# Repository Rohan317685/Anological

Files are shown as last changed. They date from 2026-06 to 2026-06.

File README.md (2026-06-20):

# Analogical 

This is Analogical; a project I've made for chipless.hackclub.com, The main goal of this project was to learn analog and not use a microcontroller! 

It is a 6 node transistor only signal network where each block drives, perturbs and destabalises the next creating a really chaotic annalog behaviour which cannot be replicated with a MCU

schematic

pcb

pcb render

| Item | Item description | Quantity | Price | Link |
|---|---|---|---|---|
| PCB | Printed Circuit Board | 5 | $5.5 | https://jlcpcb.com/ |
| 10uF capacitor | for the led transistor | 20 | $1.16 | https://www.lcsc.com/product-detail/C669099.html |
| 100nF capacitor | For decoupling | 50 | $1.07 | https://www.lcsc.com/product-detail/C89258.html |
| 10uF Electrolytic Capacitor | For decoupling | 50 | $ 1.05  | https://www.lcsc.com/product-detail/C2841113.html |
| Red LED | For showing the patterns | 20 | $ 0.73  | https://www.lcsc.com/product-detail/Light-Emitting-Diodes-LED_red_C99772.html |
| 1n41482 diode | For reverse polarity protection | 5 | $0.73 | https://www.lcsc.com/product-detail/C112342.html |
|  Pin header 1x2 | For power supply | 20 | $ 0.61  | https://www.lcsc.com/product-detail/C124375.html |
| Transistor JSCJ C1815 120~240-TA | For the transistors ofc | 40 | $  1.04 | https://www.lcsc.com/product-detail/C382004.html |
| Resistor 100k | For resisting | 100 | $0.29 | https://www.lcsc.com/product-detail/C416061.html |
| Resistor 1k | For resisting aswell | 100 | $ 0.42  | https://www.lcsc.com/product-detail/Chip-Resistor-Surface-Mount_1KR-1000-1_C95781.html |
| AMS1117-3.3 | Voltage regulator | 5 | $ 0.99  | https://www.lcsc.com/product-detail/C6186.html |
|LCSC fees |Shipping/handling fees | N/A |$7.89 | lcsc.com |

I have used the cheapest shipping options and it comes to a total off: $22.48

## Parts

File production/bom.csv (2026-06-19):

Designator | Footprint | Quantity | Value | LCSC Part #
C1, C2, C3, C4, C5, C6 | 0805 | 6 | 10uF
C10, C9 | 0805 | 2 | 100nF
C7, C8 | CP_Radial_D5.0mm_P2.00mm | 2 | 10uF
D1, D2, D3, D4, D5, D6 | LED_D3.0mm | 6 | LED
D7 | D_SOD-123 | 1 | 1N4148W
J1 | PinHeader_1x02_P2.54mm_Vertical | 1 | Conn_01x02_Pin
Q1, Q10, Q11, Q12, Q13, Q14, Q15, Q16, Q17, Q18, Q2, Q3, Q4, Q5, Q6, Q7, Q8, Q9 | TO-92_Inline | 18 | Q_NPN_BCE
R1, R11, R12, R13, R14, R15, R19, R20, R21, R22, R23, R24, R3, R4, R5, R7, R8, R9 | 0805 | 18 | 100k
R10, R16, R17, R18, R2, R6 | 0805 | 6 | 1k
U1 | SOT-223-3_TabPin2 | 1 | AMS1117-3.3

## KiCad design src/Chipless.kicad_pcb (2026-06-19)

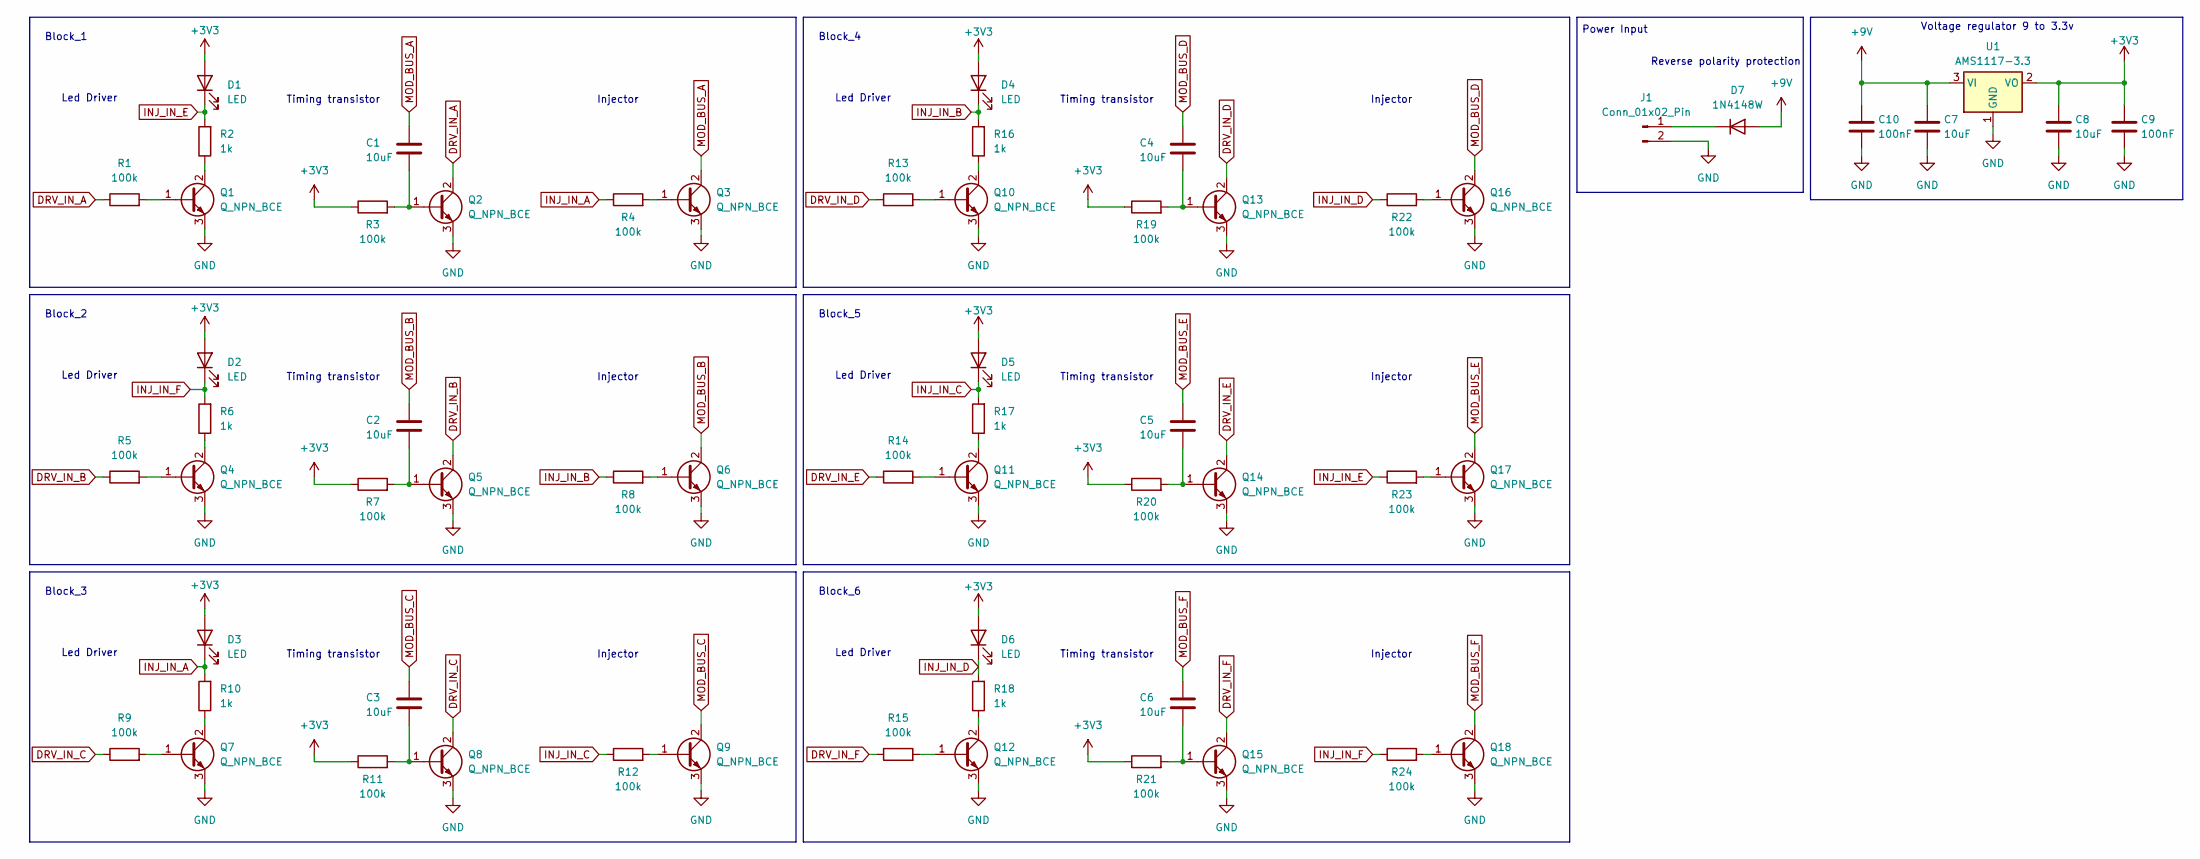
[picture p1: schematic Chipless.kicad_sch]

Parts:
C1, C2, C3, C4, C5, C6: 10uF; C_0805_2012Metric
C7, C8: 10uF; CP_Radial_D5.0mm_P2.00mm
C9, C10: 100nF; C_0805_2012Metric
D1, D2, D3, D4, D5, D6: LED; LED_D3.0mm
D7: 1N4148W; D_SOD-123
J1: Conn_01x02_Pin; PinHeader_1x02_P2.54mm_Vertical
Q1, Q2, Q3, Q4, Q5, Q6, Q7, Q8, Q9, Q10, Q11, Q12, Q13, Q14, Q15, Q16, Q17, Q18: Q_NPN_BCE; TO-92_Inline
R1, R3, R4, R5, R7, R8, R9, R11, R12, R13, R14, R15, R19, R20, R21, R22, R23, R24: 100k; R_0805_2012Metric
R2, R6, R10, R16, R17, R18: 1k; R_0805_2012Metric
U1: AMS1117-3.3; SOT-223-3_TabPin2

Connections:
+3V3: C8.1, C9.1, D1.2 (A), D2.2 (A), D3.2 (A), D4.2 (A), D5.2 (A), D6.2 (A), R3.1, R7.1, R11.1, R19.1, R20.1, R21.1, U1.2 (VO)
+9V: C7.1, C10.1, D7.2 (A), U1.3 (VI)
DRV_IN_A: Q2.2 (C), R1.1
DRV_IN_B: Q5.2 (C), R5.1
DRV_IN_C: Q8.2 (C), R9.1
DRV_IN_D: Q13.2 (C), R13.1
DRV_IN_E: Q14.2 (C), R14.1
DRV_IN_F: Q15.2 (C), R15.1
GND: C7.2, C8.2, C9.2, C10.2, J1.2, Q1.3 (E), Q2.3 (E), Q3.3 (E), Q4.3 (E), Q5.3 (E), Q6.3 (E), Q7.3 (E), Q8.3 (E), Q9.3 (E), Q10.3 (E), Q11.3 (E), Q12.3 (E), Q13.3 (E), Q14.3 (E), Q15.3 (E), Q16.3 (E), Q17.3 (E), Q18.3 (E), U1.1 (GND)
INJ_IN_A: D3.1 (K), R4.1, R10.2
INJ_IN_B: D4.1 (K), R8.1, R16.2
INJ_IN_C: D5.1 (K), R12.1, R17.2
INJ_IN_D: D6.1 (K), R18.2, R22.1
INJ_IN_E: D1.1 (K), R2.2, R23.1
INJ_IN_F: D2.1 (K), R6.2, R24.1
MOD_BUS_A: C1.1, Q3.2 (C)
MOD_BUS_B: C2.1, Q6.2 (C)
MOD_BUS_C: C3.1, Q9.2 (C)
MOD_BUS_D: C4.1, Q16.2 (C)
MOD_BUS_E: C5.1, Q17.2 (C)
MOD_BUS_F: C6.1, Q18.2 (C)
unnamed: D7.1 (K), J1.1
unnamed: Q1.1 (B), R1.2
unnamed: Q1.2 (C), R2.1
unnamed: C1.2, Q2.1 (B), R3.2
unnamed: Q3.1 (B), R4.2
unnamed: Q4.1 (B), R5.2
unnamed: Q4.2 (C), R6.1
unnamed: C2.2, Q5.1 (B), R7.2
unnamed: Q6.1 (B), R8.2
unnamed: Q7.1 (B), R9.2
unnamed: Q7.2 (C), R10.1
unnamed: C3.2, Q8.1 (B), R11.2
unnamed: Q9.1 (B), R12.2
unnamed: Q10.1 (B), R13.2
unnamed: Q10.2 (C), R16.1
unnamed: Q11.1 (B), R14.2
unnamed: Q11.2 (C), R17.1
unnamed: Q12.1 (B), R15.2
unnamed: Q12.2 (C), R18.1
unnamed: C4.2, Q13.1 (B), R19.2
unnamed: C5.2, Q14.1 (B), R20.2
unnamed: C6.2, Q15.1 (B), R21.2
unnamed: Q16.1 (B), R22.2
unnamed: Q17.1 (B), R23.2
unnamed: Q18.1 (B), R24.2

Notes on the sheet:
Led Driver
Block_3
Reverse polarity protection
Block_6
Voltage regulator 9 to 3.3v
Power Input
Timing transistor
Block_2
Injector
Block_1
Block_5
Block_4

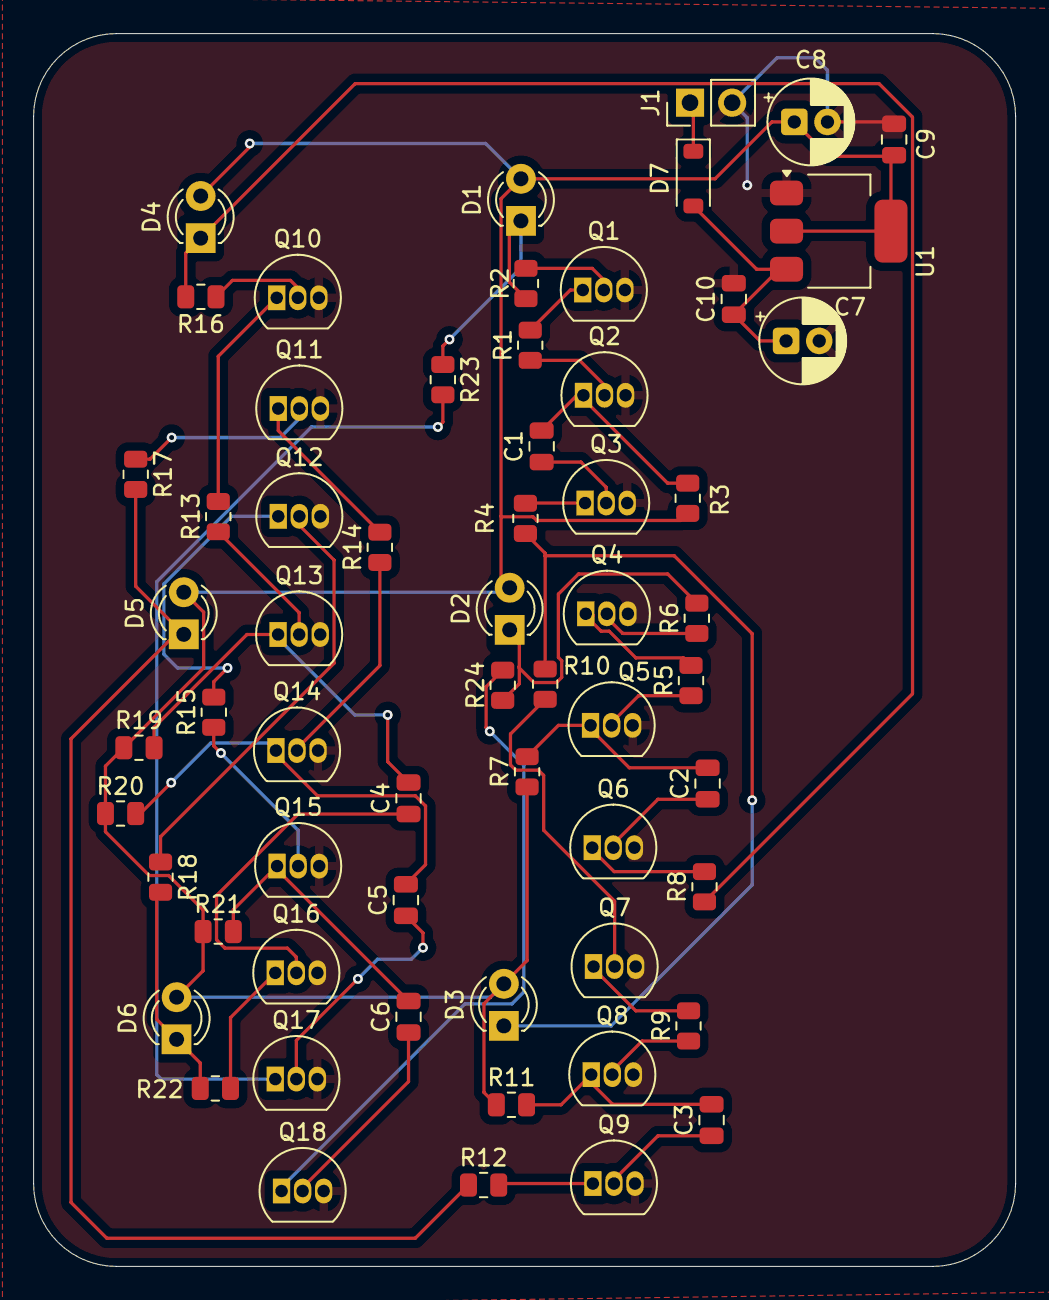
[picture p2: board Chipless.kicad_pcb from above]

Board: 2 copper layers, 59.2 x 74.4 mm, 61 parts (0 on the bottom side), 46 nets.
